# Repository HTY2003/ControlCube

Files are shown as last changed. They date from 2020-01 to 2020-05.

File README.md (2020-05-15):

# ControlCube
A cube of keyboard switches.
It was very bad.
It's taken apart now.
But this is a log :D

This repo includes:
* Rhino3D Design Files for the case and keycaps
* STL exports of the design files for easy viewing
* EAGLE design files for the controller board, switchplate, and switchboard
* Gerber exports of the design files for easy viewing

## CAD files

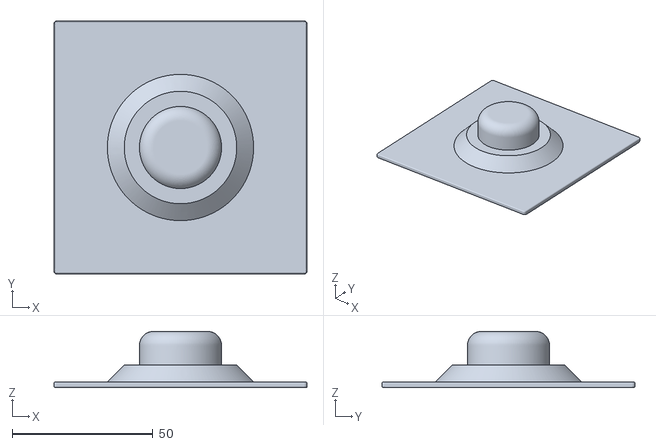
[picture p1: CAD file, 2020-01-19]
Control Cube Base.stl
90.0 x 90.0 x 20.0

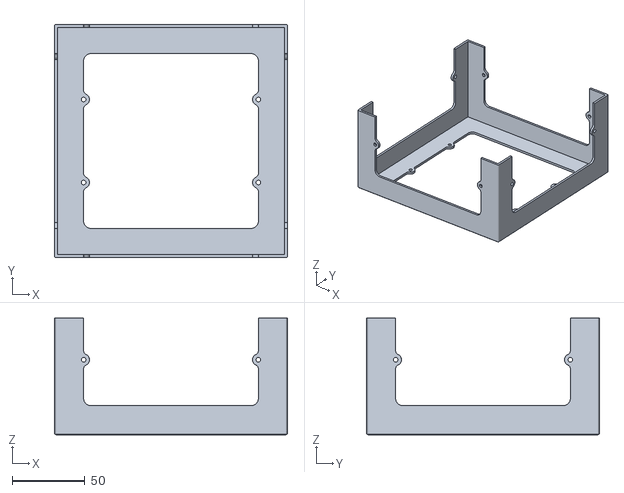
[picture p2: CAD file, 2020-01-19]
Control Cube.stl
160.0 x 160.0 x 80.0

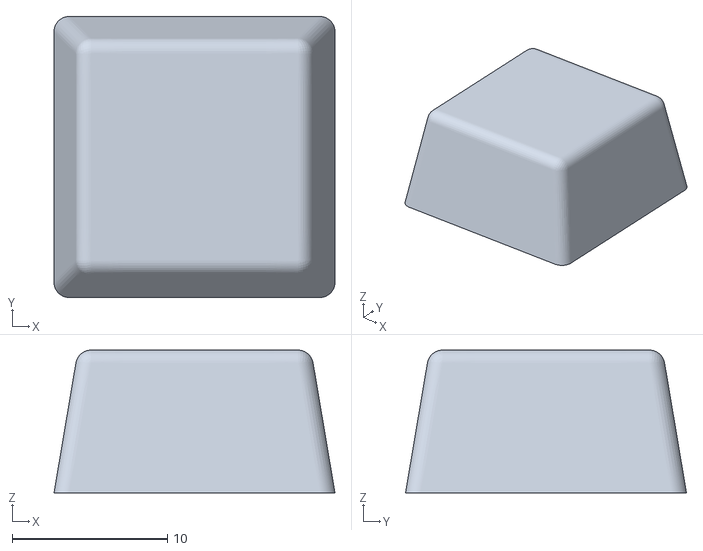
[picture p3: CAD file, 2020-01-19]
MX Keycap.stl
18.1 x 18.1 x 9.20

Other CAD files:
Control Cube and Base.3dm
MX Keycap.3dm

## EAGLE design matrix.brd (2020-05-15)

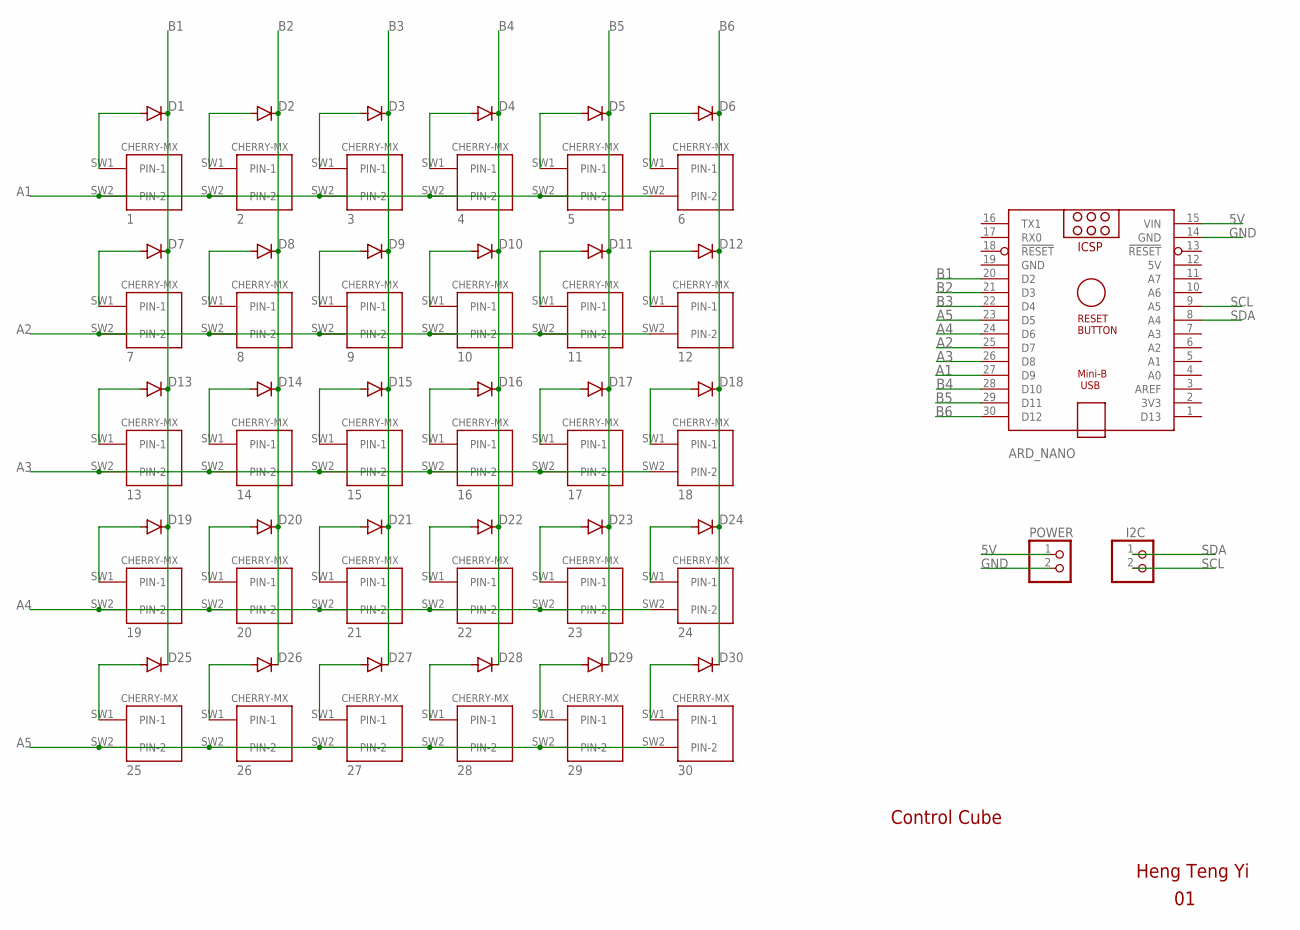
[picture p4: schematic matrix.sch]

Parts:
1, 2, 3, 4, 5, 6, 7, 8, 9, 10, 11, 12, 13, 14, 15, 16, 17, 18, 19, 20, 21, 22, 23, 24, 25, 26, 27, 28, 29, 30: CHERRY-MX
ARD_NANO: ARDUINO_NANO
D1, D2, D3, D4, D5, D6, D7, D8, D9, D10, D11, D12, D13, D14, D15, D16, D17, D18, D19, D20, D21, D22, D23, D24, D25, D26, D27, D28, D29, D30: 1N4148DO35-7; DO35-7
I2C: PINHD-1X2/90; 1X02/90
POWER: PINHD-1X2/90; 1X02/90

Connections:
5V: ARD_NANO.12 (5V), ARD_NANO.15 (VIN), POWER.1
A1: 1.SW2 (PIN-2), 2.SW2 (PIN-2), 3.SW2 (PIN-2), 4.SW2 (PIN-2), 5.SW2 (PIN-2), 6.SW2 (PIN-2), ARD_NANO.27 (D9)
A2: 7.SW2 (PIN-2), 8.SW2 (PIN-2), 9.SW2 (PIN-2), 10.SW2 (PIN-2), 11.SW2 (PIN-2), 12.SW2 (PIN-2), ARD_NANO.25 (D7)
A3: 13.SW2 (PIN-2), 14.SW2 (PIN-2), 15.SW2 (PIN-2), 16.SW2 (PIN-2), 17.SW2 (PIN-2), 18.SW2 (PIN-2), ARD_NANO.26 (D8)
A4: 19.SW2 (PIN-2), 20.SW2 (PIN-2), 21.SW2 (PIN-2), 22.SW2 (PIN-2), 23.SW2 (PIN-2), 24.SW2 (PIN-2), ARD_NANO.24 (D6)
A5: 25.SW2 (PIN-2), 26.SW2 (PIN-2), 27.SW2 (PIN-2), 28.SW2 (PIN-2), 29.SW2 (PIN-2), 30.SW2 (PIN-2), ARD_NANO.23 (D5)
B1: ARD_NANO.20 (D2), D1.C, D7.C, D13.C, D19.C, D25.C
B2: ARD_NANO.21 (D3), D2.C, D8.C, D14.C, D20.C, D26.C
B3: ARD_NANO.22 (D4), D3.C, D9.C, D15.C, D21.C, D27.C
B4: ARD_NANO.28 (D10), D4.C, D10.C, D16.C, D22.C, D28.C
B5: ARD_NANO.29 (D11), D5.C, D11.C, D17.C, D23.C, D29.C
B6: ARD_NANO.30 (D12), D6.C, D12.C, D18.C, D24.C, D30.C
GND: ARD_NANO.14 (GND), ARD_NANO.19 (GND), POWER.2
unnamed: 1.SW1 (PIN-1), D1.A
unnamed: 2.SW1 (PIN-1), D2.A
unnamed: 3.SW1 (PIN-1), D3.A
unnamed: 4.SW1 (PIN-1), D4.A
unnamed: 5.SW1 (PIN-1), D5.A
unnamed: 6.SW1 (PIN-1), D6.A
unnamed: 7.SW1 (PIN-1), D7.A
unnamed: 8.SW1 (PIN-1), D8.A
unnamed: 9.SW1 (PIN-1), D9.A
unnamed: 10.SW1 (PIN-1), D10.A
unnamed: 11.SW1 (PIN-1), D11.A
unnamed: 12.SW1 (PIN-1), D12.A
unnamed: 13.SW1 (PIN-1), D13.A
unnamed: 14.SW1 (PIN-1), D14.A
unnamed: 15.SW1 (PIN-1), D15.A
unnamed: 16.SW1 (PIN-1), D16.A
unnamed: 17.SW1 (PIN-1), D17.A
unnamed: 18.SW1 (PIN-1), D18.A
unnamed: 19.SW1 (PIN-1), D19.A
unnamed: 20.SW1 (PIN-1), D20.A
unnamed: 21.SW1 (PIN-1), D21.A
unnamed: 22.SW1 (PIN-1), D22.A
unnamed: 23.SW1 (PIN-1), D23.A
unnamed: 24.SW1 (PIN-1), D24.A
unnamed: 30.SW1 (PIN-1), D30.A
unnamed: 29.SW1 (PIN-1), D29.A
unnamed: 28.SW1 (PIN-1), D28.A
unnamed: 27.SW1 (PIN-1), D27.A
unnamed: 25.SW1 (PIN-1), D25.A
unnamed: 26.SW1 (PIN-1), D26.A
SCL: ARD_NANO.9 (A5), I2C.2
SDA: ARD_NANO.8 (A4), I2C.1

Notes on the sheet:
Heng Teng Yi
Control Cube

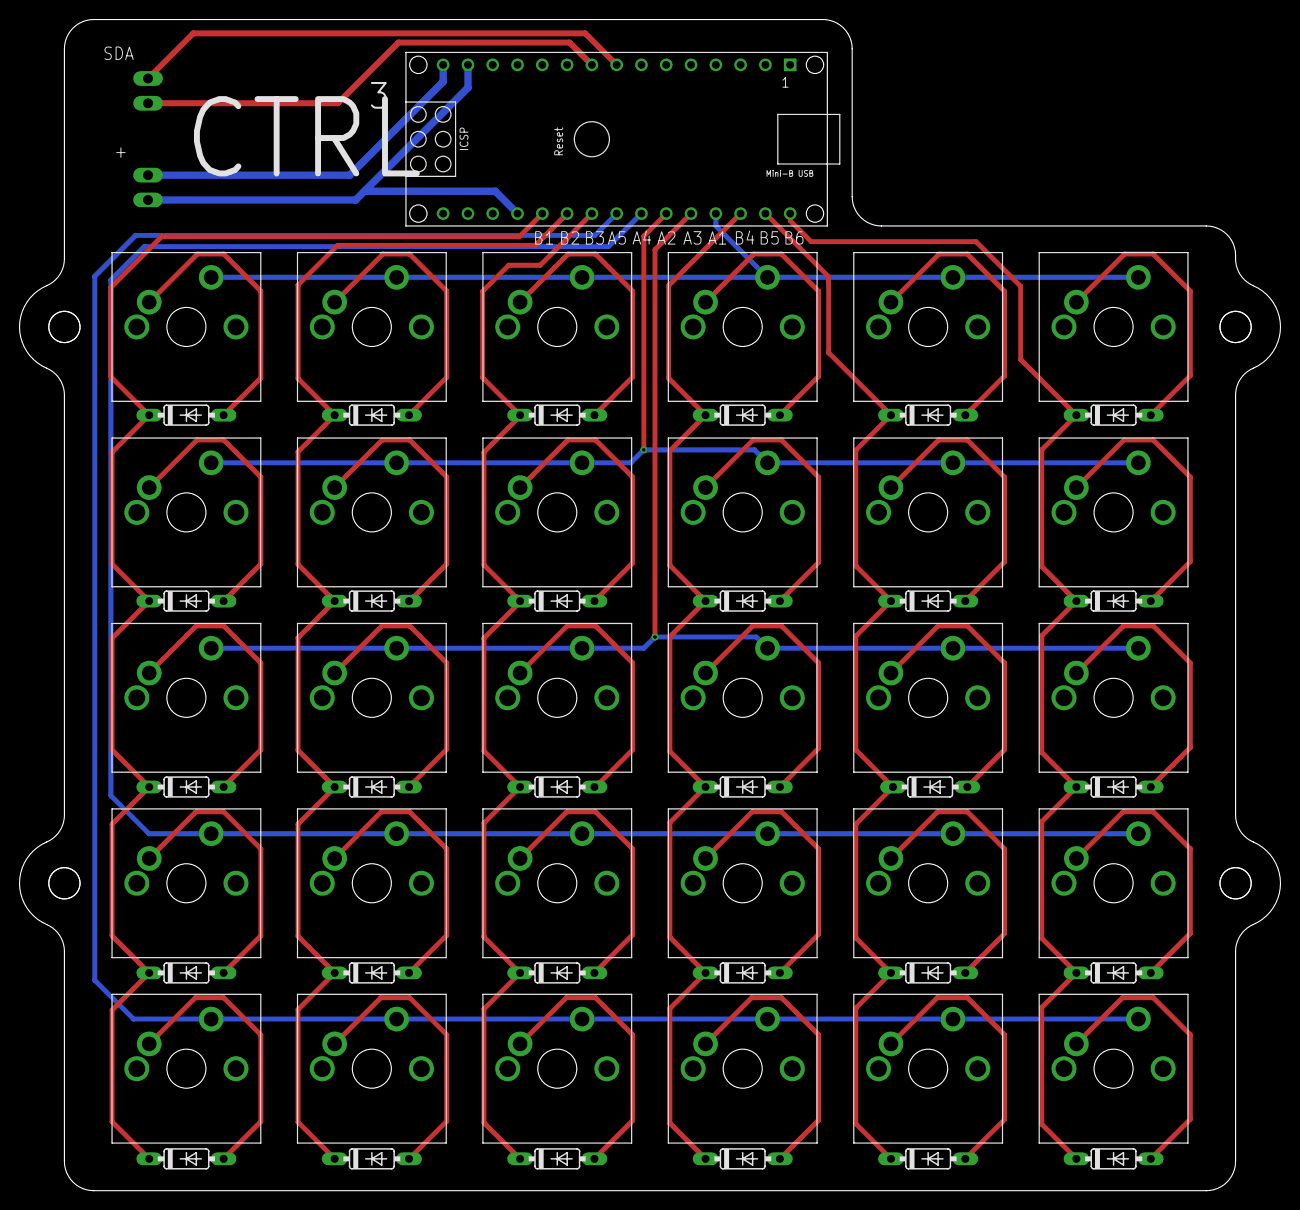
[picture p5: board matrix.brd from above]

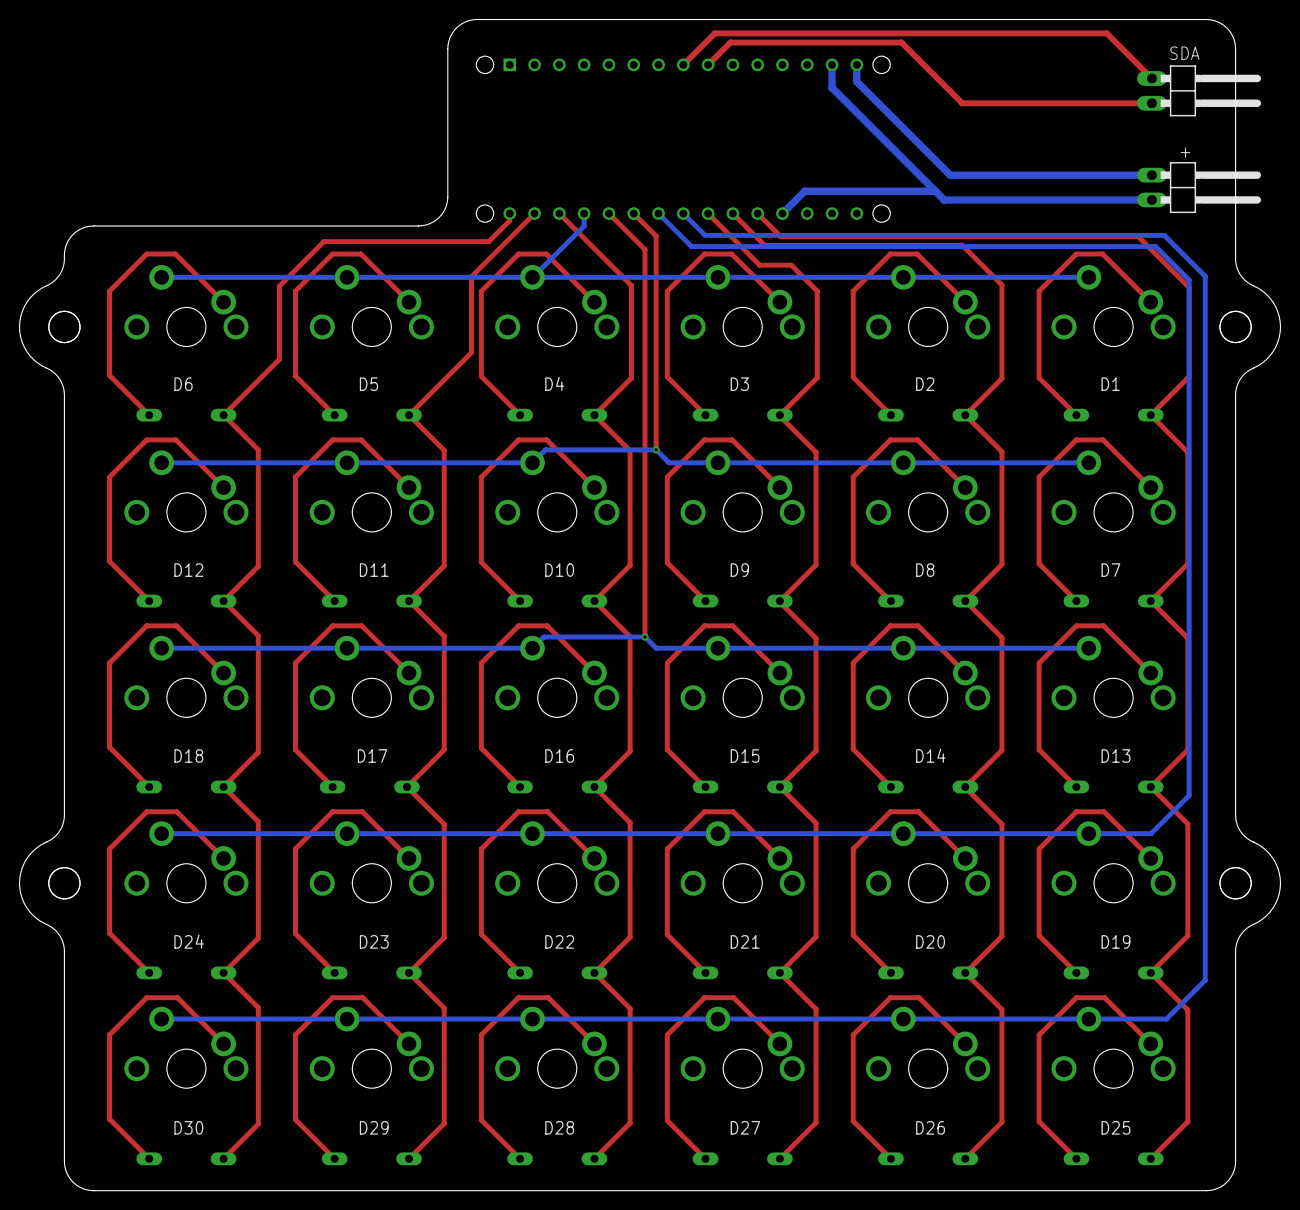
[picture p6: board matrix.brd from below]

Board: 2 copper layers, 129.2 x 120.0 mm, 63 parts (2 on the bottom side), 45 nets.

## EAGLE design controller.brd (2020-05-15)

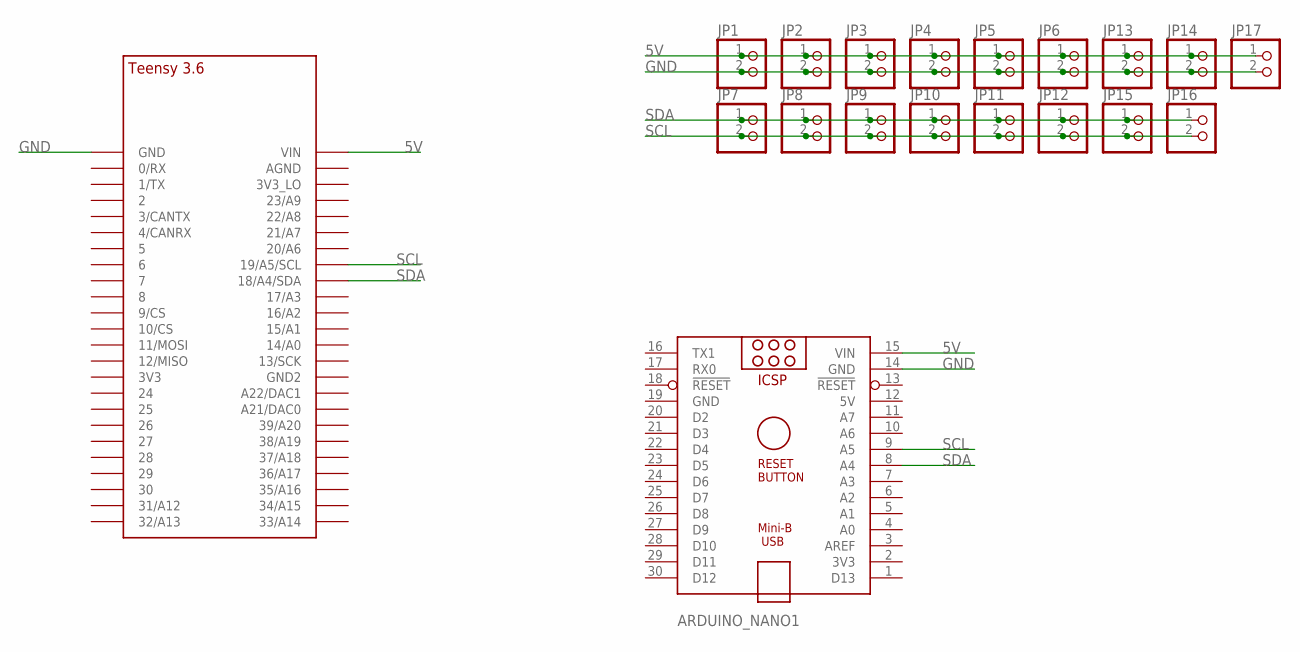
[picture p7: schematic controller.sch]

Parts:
ARDUINO_NANO1: ARDUINO_NANO
JP1, JP2, JP3, JP4, JP5, JP6, JP7, JP8, JP9, JP10, JP11, JP12, JP13, JP14, JP15, JP16, JP17: PINHD-1X2; 1X02
U$1: TEENSY_3.5/3.6_BASIC

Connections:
5V: ARDUINO_NANO1.12 (5V), ARDUINO_NANO1.15 (VIN), JP1.1, JP2.1, JP3.1, JP4.1, JP5.1, JP6.1, JP13.1, JP14.1, JP17.1, U$1.VIN
GND: ARDUINO_NANO1.14 (GND), ARDUINO_NANO1.19 (GND), JP1.2, JP2.2, JP3.2, JP4.2, JP5.2, JP6.2, JP13.2, JP14.2, JP17.2, U$1.GND
SCL: ARDUINO_NANO1.9 (A5), JP7.2, JP8.2, JP9.2, JP10.2, JP11.2, JP12.2, JP15.2, JP16.2, U$1.19/A5/SCL
SDA: ARDUINO_NANO1.8 (A4), JP7.1, JP8.1, JP9.1, JP10.1, JP11.1, JP12.1, JP15.1, JP16.1, U$1.18/A4/SDA

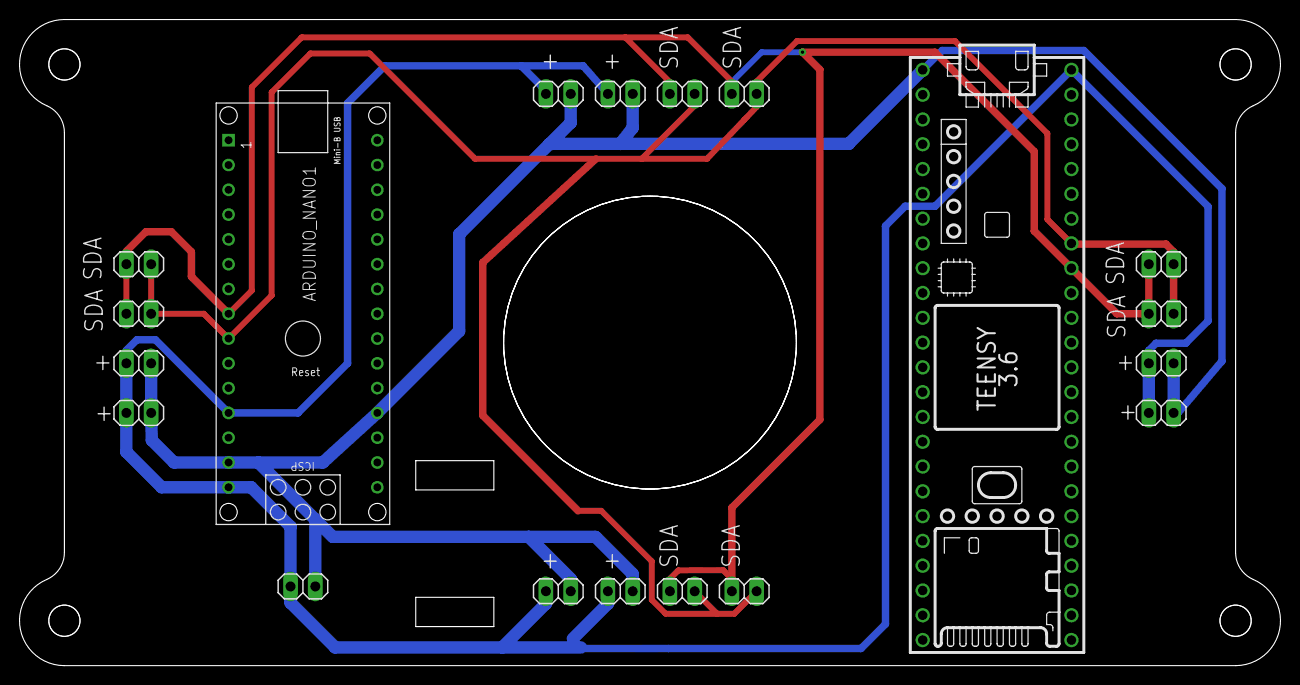
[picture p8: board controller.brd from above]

Board: 2 copper layers, 129.2 x 66.2 mm, 19 parts (0 on the bottom side), 4 nets.

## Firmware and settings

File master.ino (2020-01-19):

#include <Wire.h>

int previous, keycounter, mod, key, side, column, row;
int settings[5][6][5][3][10];

//Common Windows Shortcuts
int copee[3][10] = {{MODIFIERKEY_CTRL,KEY_C,0,0,0,0,0,0,0,0},{},{}};
int paste[3][10] = {{MODIFIERKEY_CTRL,KEY_V,0,0,0,0,0,0,0,0},{},{}};

//Media Controls
int syssleep[3][10] = {{KEY_SYSTEM_SLEEP,0,0,0,0,0,0,0,0,0},{},{}};
int syswake[3][10] = {{KEY_SYSTEM_WAKE_UP,0,0,0,0,0,0,0,0,0},{},{}};


//AutoCAD
int line[3][10] = {{KEY_L,KEY_I,KEY_N,KEY_ENTER,0,0,0,0,0,0},{},{}};
int circle[3][10] = {{KEY_C,KEY_I,KEY_R,KEY_ENTER,0,0,0,0,0,0},{},{}};

void setMacro(int side, int column, int row, int combinations[3][10]) {
  for (int a = 0; a < 3; a++) {
    for (int b = 0; b < 10; b++) {
      settings[side][column][row][a][b] = combinations[a][b];
    }
  }
}

void activateMacro(int macro[3][10]) {
  for (int i = 0; i<3;i++) {
    //reset keys
    mod = 0;
    keycounter = 0;
    Keyboard.set_modifier(0);
    Keyboard.set_key1(0);
    Keyboard.set_key2(0);
    Keyboard.set_key3(0);
    Keyboard.set_key4(0);
    Keyboard.set_key5(0);
    Keyboard.set_key6(0);
    //set new keys
    for (int j = 0; j<10;j++) {
      key = macro[i][j];
      if (key == MODIFIERKEY_CTRL || key == MODIFIERKEY_SHIFT || key == MODIFIERKEY_ALT || key == MODIFIERKEY_GUI){
        if (mod > 0) mod = mod | key;
        if (mod == 0) mod = key;
      } else if (key > 0) {
          switch (keycounter) {
              case 5: Keyboard.set_key6(key); break;
              case 4: Keyboard.set_key5(key); break;
              case 3: Keyboard.set_key4(key); break;
              case 2: Keyboard.set_key3(key); break;
              case 1: Keyboard.set_key2(key); break;
              case 0: Keyboard.set_key1(key); break;
            }
          if (keycounter < 6) keycounter++;
      }
      //send report
      Keyboard.set_modifier(mod);
      Keyboard.send_now();
    }
  }
}
void setup() {
  Wire.setClock(400000);
  Wire.begin(0);
  Serial.begin(9600);
  previous = millis();
  Wire.onReceive(receiveEvent);
  mod = keycounter = 0;
  setMacro(1,0,0, copee);
  setMacro(1,1,0, paste);

  setMacro(1,0,1, syssleep);
  setMacro(1,1,1, syswake);

  setMacro(1,0,2, line);
  setMacro(1,1,2, circle);
  
  Keyboard.end();
  Keyboard.begin();
}

void loop() {
}

void receiveEvent(int numBytes) {
  side = Wire.read();
  column = Wire.read();
  row = Wire.read();
  if ((millis() - previous) > 200) {
    activateMacro(settings[side][column][row]);
    previous = millis();
  }
}

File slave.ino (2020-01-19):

#include <Wire.h>

int rows[5]={9,7,8,6,5};
int columns[6]={2,3,4,10,11,12};
int buf[2];
int counter = 0;
int x = 1;

void setup() {
  Serial.begin(9600);
  Wire.setClock(400000);
  Wire.begin(x);
  for (int r = 0; r<5; r++) {
    pinMode(rows[r], INPUT_PULLUP);
  }
  for (int c = 0; c<6; c++) {
    pinMode(columns[c], OUTPUT);
    digitalWrite(columns[c], HIGH);
  }
}

void loop() {
  for (int c = 0; c<6; c++) {
    digitalWrite(columns[c], LOW);
    for (int r = 0; r<5; r++) {
      if (!digitalRead(rows[r])) {
        Serial.print("Column: ");
        Serial.print(c);
        Serial.print("Row:");
        Serial.println(r);
        Wire.beginTransmission(0);
        Wire.write(x);
        Wire.write(c);
        Wire.write(r);
        Wire.endTransmission();
        if (counter < 12) {
          buf[counter] = c;
          buf[counter+1] = r;
          counter += 2;
        } else {
          buf[0] = c;
          buf[1] = r;
          counter = 2;
        }
      }
    }
    digitalWrite(columns[c],HIGH);
  }
}

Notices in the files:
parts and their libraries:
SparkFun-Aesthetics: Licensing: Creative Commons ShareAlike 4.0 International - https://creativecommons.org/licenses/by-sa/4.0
